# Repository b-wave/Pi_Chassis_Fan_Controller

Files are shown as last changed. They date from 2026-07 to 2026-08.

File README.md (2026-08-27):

# A Pi Chassis Fan Controller - Interface Board 
This describes a small board to interface a 5V, 4-wire fan in a controller cabinet with a Raspberry Pi controller.  The fan I am using is a **GeeekPi** 40x40x10mm 4-wire Fan, **Model F-0028**.  [https://www.amazon.com/GeeekPi-Raspberry-40x40x10mm-Adjustment-Included/dp/B0CL41RG93] 

The JST SH connector on the board should be compatible with the Raspberry Pi's Fan Connector. But that connector did not exist on a PI3. You **DO NOT** need this board to control the processor fan, it is intended to actively ventilate an enclosed, wall mounted cabinet. Yes, it is over-designed and has extras such as a static ring ground and ESD diodes - all are probably overkill but it is cheap insurance.  Yes, there are three revisions. I started with a two-wire fan, then three-wire, and finally with this 4-wire version with 100% less transistors.  It mainly just converts the short JST connector into a standard screw terminal. 

Although I provide a separate 2-pin input voltage connector terminal block (J3) it is intended for 5-Volts only. Its purpose is to not stress the **Raspberry Pi's** Power supply.  Although it should be perfectly fine to run the recommended fan directly off of the +5V, since it was designed to run off of the fan connector on the newer boards. 

By the way, that connector is reverse voltage protected in case you get the power leads reversed - you *should not* damage the Pi.

<h2 align="center">⚡ CAUTION ⚡</h2>

Be careful if using a 12V fan! *Damage may occur to 3v3 inputs and you may fry your Pi* 

It may need a **level shifter** if it does not provide 5V or pin compatible signals (TACH and maybe the PWM) - verify pin voltages before connecting to PI.  If they are open collector, the 3v3 reference on the 10k pullup should take care of that. 

<p align="center">
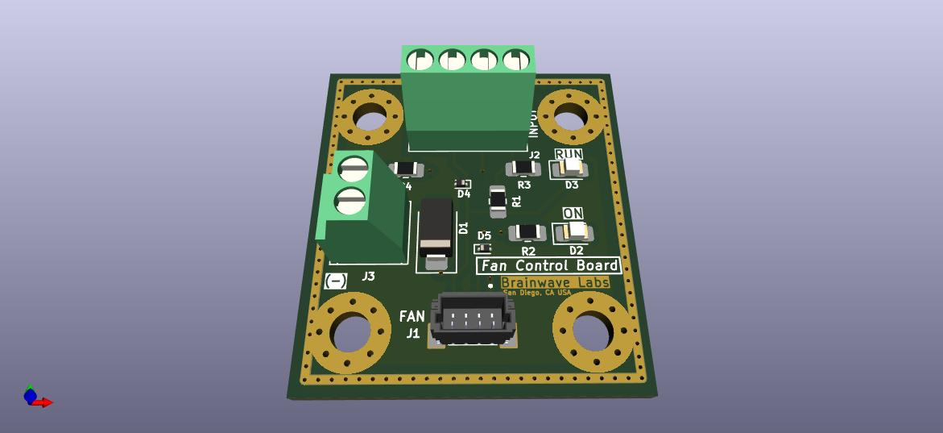
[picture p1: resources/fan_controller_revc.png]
3D View Generated
  
</p>

## Overview
I am working on a Raspberry Pi 4 controlled LTE gateway using a small DIN rail enclosure.  The planned locations are at fairly remote, and the equipment will be enclosed in a small cabinet so active ventilation is required.  This board was needed to simplify installation and to provide some visual and remote feedback.  This is a fairly simple board that is tailored to my specific installations, but I may expand it to be more general purpose.  In any case, it provides a neat interface to control a cabinet fan I finally settled on this design:

<p align="center">
  Schematic
</p>

The schematic is pretty straightforward.  It uses a hybrid SMT + Through-hole technologies. The ESD diodes wee exceedingly hard to hand solder *so I left them off the prototype,* but the rest of the board should be OK.  

---

## Hardware Description
The hardware combines familiar building blocks with some added protection from the very warm (hot) and dry environment.   I may put ESD tape and spray in my enclosure as it is intended to run in a dry dusty environment. 

  *I am not 100% sure if the "Ring Ground" is implemented correctly.  ...But it looks cool?*

<p align="center">
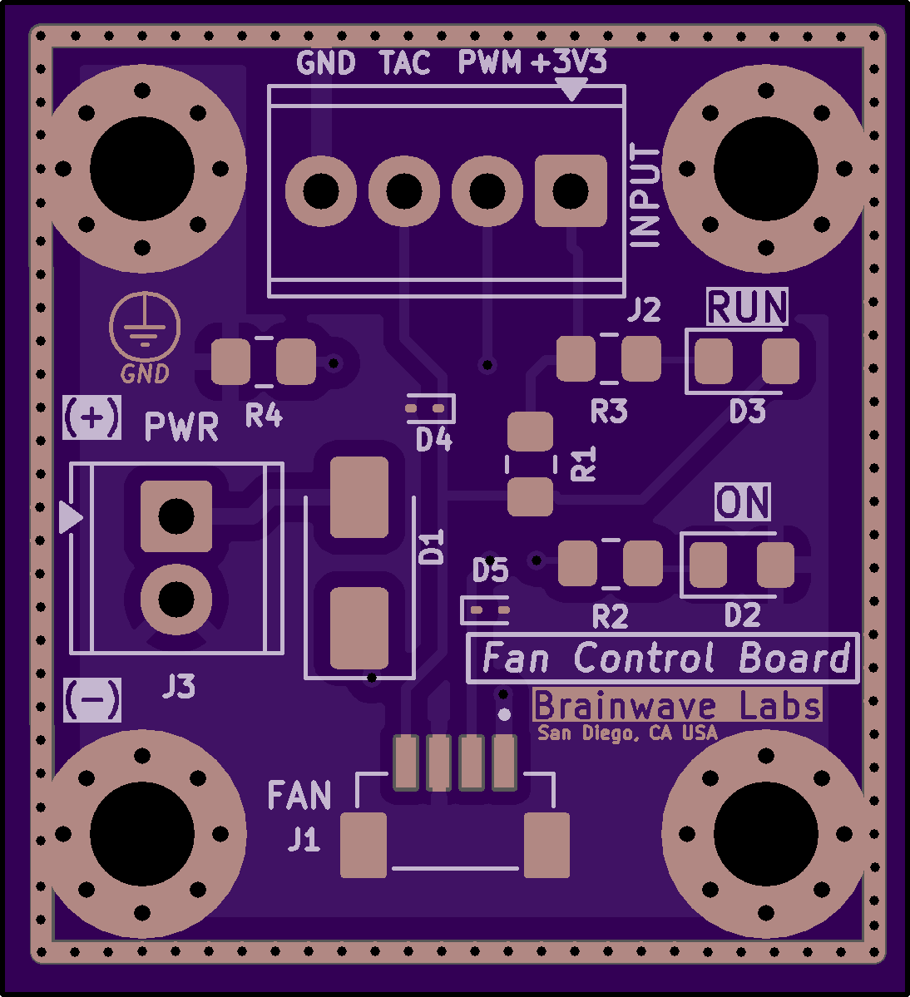
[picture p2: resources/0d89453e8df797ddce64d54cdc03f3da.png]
PCB
  
</p>

It is a approximately one inch square and is designed to fit on a small DIN rail carrier. The board is available on OSHPARK Shared and I will leave a link. [ www.oshpark](https://oshpark.com) ~The shown image is an early version and some components are moved. I will update and add a link after testing!~  

            Hole Spacing: 0.75" x 0.80" (19.0mm x 20.3mm)
            Board Outline: 1.10" x 1.20" (27.6mm x 30.2 mm)

  - The LEDs give a visual indication of the fan's operation, since in many cases the fan cannot be seen or heard. 

### Wiring: 
The fan controller interface board was designed with screw blocks so you can use wires (stranded 20-22 AWG is recommend) simply strip your wire tips back ~1/8", slide them into the screw terminals, and screw to clamp them down tightly. Alternately, DuPont jumper wires should work, acting like ferrules to keep the wires from pinching. Since these connectors are on 0.1" (2.54mm) centers so you can alternately use regular pin headers and DuPont jumpers.

### Input connector: 
This connector should be compatible with most 4-wire 5V cooling fans. It helps in two ways. First you just plug in the fan, it provides an interface for the fan's connector. Secondly, since this board is meant for use in an enclosure, the fan wires usually are not long enough, so simply locate this board near the fan and run longer wires back to the Pi.

### Power Connector: 
J3 pins may be used to input power for the fan. A second external power supply may be used to keep load off of the 5V Raspberry power supply. An external 5V supply should be used but it is possible to use a 12V fan but be mindful of the signals (TACH and PWM) may not have GPIO compatible levels.  But typically the TACH signal is an open collector (or Drain) type so you can use the pull up and the 3v3 reference will generate the proper input signal.  

 - Fan 5V Power (J3) Pin (1) (Red) ──► Screw into terminal 5V (Pin 2 or 4)
 - Fan 5V Ground (J3) Pin (2) (Black) ──► Screw into terminal GND (Pin 6, 9, or 14)
   *Or use an external 5V supply* 

### Signal Pins: 
J2 is the signal interface to the Raspberry PI's GPIOs needed to control and monitor the fan. Two GPIOs are needed, one output for the **PWM** and input for the **TAC (FG)** wires. 

 - Fan 3 Volt Reference (RED) ──► Screw into terminal (3V3)
 - Fan PWM Control Signal (Blue) ──► Screw into terminal GPIO 12 (Pin 32)
 - Fan System Ground (Black) ──► Screw into terminal GND (Pin 6, 9, or 14)
 - Fan TACH (or FG) Speed Feedback (Yellow) ──► Screw into terminal GPIO 13 (Pin 33)
  
    - **NOTE:**
      - The wire colors are fairly standard - but they should match the Pi-Fan connectors
      - If the PWM wire connection is open the fan will run at full speed. If you don't want that put a large (10k - 100k) resistor to ground 

### The "ON" LED: 
      
The "Fan On" or "Drive" Indicator (Green or Red)

This LED is wired to the PWM lines powering the fan. When the fan is running at full speed (100% PWM) it is ON full, when it is OFF ( 0% PWM) the fan is OFF. There is a slight dim glow green whenever the fan has power and is being driven by the PWM signal in different speeds it also changes brightness. 

  - **NOTE:** This LED can also be used to FLASH a code if the fan stalls to aid in servicing since it is strictly an output. 
  
### The "RUN" LED: 
The "Fan Spinning" Indicator (Yellow or Blue). 

This LED is wired to the TACH  line to monitor it visually. Sometimes this signal is labeled Frequency Generator (FG). 

When the fan is stalled or off, the LED either stays solid or completely dark. When the fan spins at high speed (e.g., 3000 RPM), the TACH pulses occur so quickly (100 times per second) that human eyes perceive the flashing as a continuous, soft glow. If the fan slows down or begins to struggle, you will visually notice the light dimming or starting to flicker.  If it stops with the LED ON it will turn off after a few seconds. this is normal behavior of these fans to protect against a stall it shuts the control circuits down.  It may even flash occasionally on some fans to test to see if the obstruction is clear. 

---

## Example Software

*Coming Soon! - no, really.  Check back*

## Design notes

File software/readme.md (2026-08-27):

# Example Scripts
These were generated scripts and some are not really tested. But you should be able to modify for your own use. 
--

## The Hardware Test Python Script 

**[fan_thermal_test.py]**

This Python script uses the **gpiozero** library to test the fan and the PCB. It reads the Pi SoC and the ambient temperature (via the RTC module). This script does work on my hardware but you may need to modify it to run. You should see a smooth linear climb for example: 
  
*Start at 0% duty cycle climbing to 750 RPM at 25% duty cycle up to a whopping 3,900 RPM at 100% means your PCB's hardware pull-up circuit and the software interrupt logic are working flawlessly.*

NOTE: 

- Some settings I used on my Raspberry Pi 3 system is running a development branch of Debian Trixie (Debian 13) with Linux kernel 6.18.34+rpt-rpi-v8
-   While 25,000 Hz (25kHz) is the ideal hardware standard for computer fans to prevent a high-pitched whining noise, a software-driven GPIO pin using lgpio cannot handle a frequency that high and throws a 'bad PWM frequency' error. So to bypass this error and see the fan spin, we can change the frequency down to a standard value that lgpio accepts, like 100 Hz. Because 100 Hz is in the human audible spectrum, the fan motor might make a faint humming sound during the test—this is completely normal for software PWM!
-   Also, the interface board has its own pull up resistor on the TACH line, so I turned off the pull up on the GPIO as well. 
   
```
# 25kHz is the industrial standard target frequency for 4-wire fans
fan_pwm = PWMOutputDevice(PWM_PIN, frequency=100, initial_value=0.0)
fan_tach = DigitalInputDevice(TACH_PIN, pull_up=None, active_state=False) # Using the PCB's 3V3 hardware pull-up
```

## The Failsafe Monitoring Python Script

**[Fan_Failsafe_Monitor.py]**

This Python script uses the gpiozero library to watch for pulses on the FG pin. It calculates the RPM, and if the fan is supposed to be running but stalls out (RPM drops to 0), it triggers your power-saving protective mode
--

## System Test with Logging and Alerts Python Script

**[Fan_System_Test_Example.py]**
This is an example operational/test script hat reads temperatures from two points in the chassis, the SoC and the ambient temperature (the termal sensor in the RTC chip) to help define and set the setpoints.  The test's alerts are shown with ntfy.com  
--

##  Complete Automated Python Script

**[Fan_Control.py]**
This script uses the gpiozero library to handle both pins. It samples the Raspberry Pi's internal CPU temperature every few seconds. If the Pi gets warm, it turns on the fan and scales the fan's speed using PWM. If the Pi cools down, it shuts off the fan completely  (PWM = 0%) to save power.
--

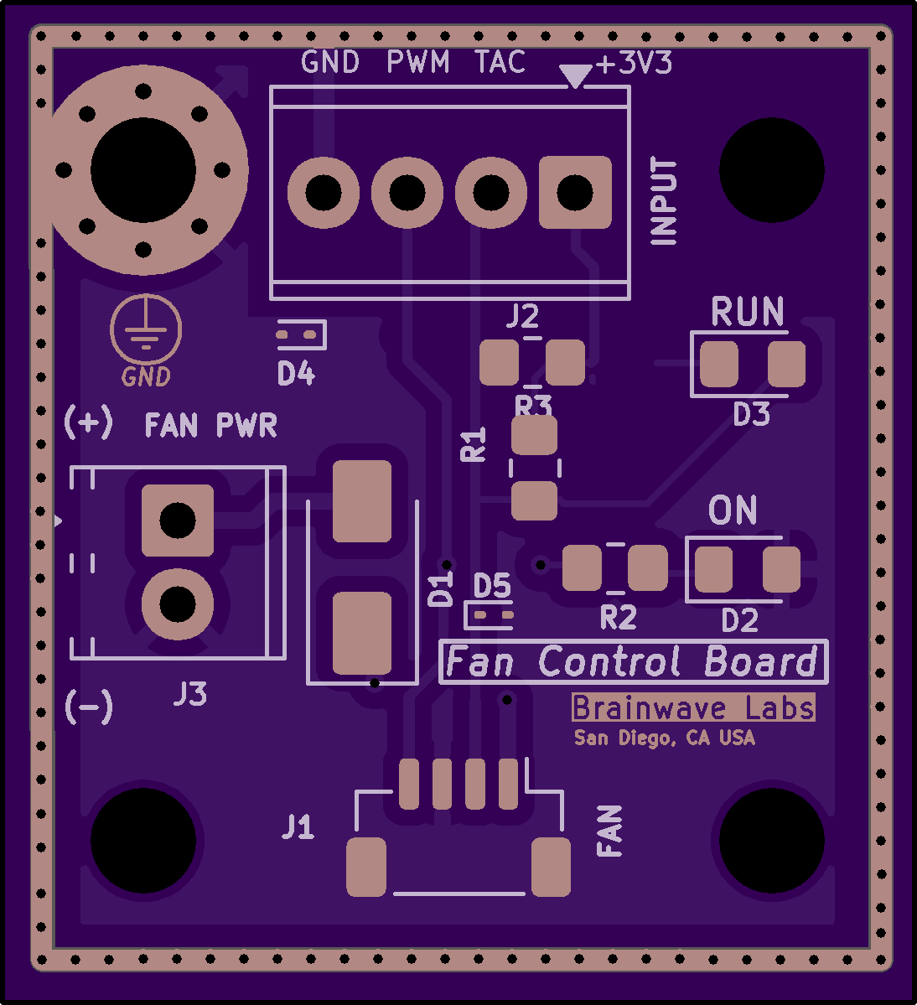
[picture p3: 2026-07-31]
resources/f2cf50859baaec17621ed978b20d583c.png

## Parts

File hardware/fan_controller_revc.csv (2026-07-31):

Reference | Value | Footprint | Datasheet | Qty | DNP | Exclude from BOM | Exclude from Board
D1 | SS14 | Library:D_SMA | https://www.digikey.com/en/products/detail/onsemi/SS14/965474 | 1
D2 | ON | Library:LED_0805_2012Metric_Pad1.15x1.40mm_HandSolder | ~https://www.digikey.com/en/products/detail/liteon/LTST-C190KGKT/386815 | 1
D3 | RUN | Library:LED_0805_2012Metric_Pad1.15x1.40mm_HandSolder | https://www.digikey.com/en/products/detail/liteon/LTST-C190KSKT/386819 | 1
D4 | ESD9B3.3ST5G | Diode_SMD:D_SOD-923 | https://www.digikey.com/en/products/detail/onsemi/ESD9R3-3ST5G/1961067 | 1
D5 | ESD9B3.3ST5G | Library:D_SOD-923 | https://www.digikey.com/en/products/detail/onsemi/ESD9R3-3ST5G/1961067 | 1
H1,H2,H4 | MountingHole | Library:MountingHole_3.2mm_M3_DIN965 | ~ | 3 |  | Excluded from BOM
H3 | MountingHole_Pad | Library:MountingHole_3.2mm_M3_Pad_Via | See Note | 1 |  | Excluded from BOM
J1 | FAN | Library:ADAFRUIT_4328 | https://www.digikey.com/en/products/detail/jst-sales-america-inc/BM04B-SRSS-TB/926696 | 1
J2 | INPUT | Library:TerminalBlock_Phoenix_MPT-0,5-4-2.54_1x04_P2.54mm_Horizontal | https://www.digikey.com/en/products/detail/on-shore-technology-inc/OSTVN04A150/1588864 | 1
J3 | PWR | Library:TerminalBlock_Phoenix_MPT-0,5-2-2.54_1x02_P2.54mm_Horizontal | ~https://www.digikey.com/en/products/detail/adafruit-industries-llc/2138/6827101 | 1
R1 | 10k | Library:R_0805_2012Metric_Pad1.20x1.40mm_HandSolder | https://www.digikey.com/en/products/detail/vishay-dale/CRCW080510K0FKEA/1175751 | 1
R2,R3 | 1K | Library:R_0805_2012Metric_Pad1.20x1.40mm_HandSolder | https://www.digikey.com/en/products/detail/vishay-dale/CRCW08051K00FKEA/1175637 | 2

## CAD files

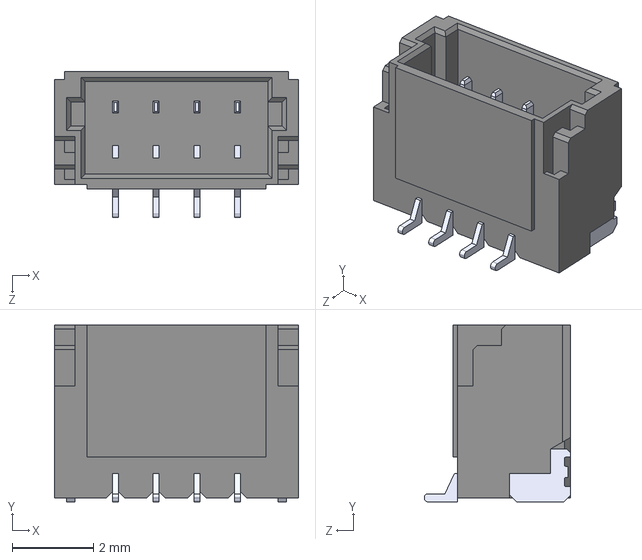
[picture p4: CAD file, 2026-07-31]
hardware/4328/4328.step
6.00 x 4.35 x 3.60 mm

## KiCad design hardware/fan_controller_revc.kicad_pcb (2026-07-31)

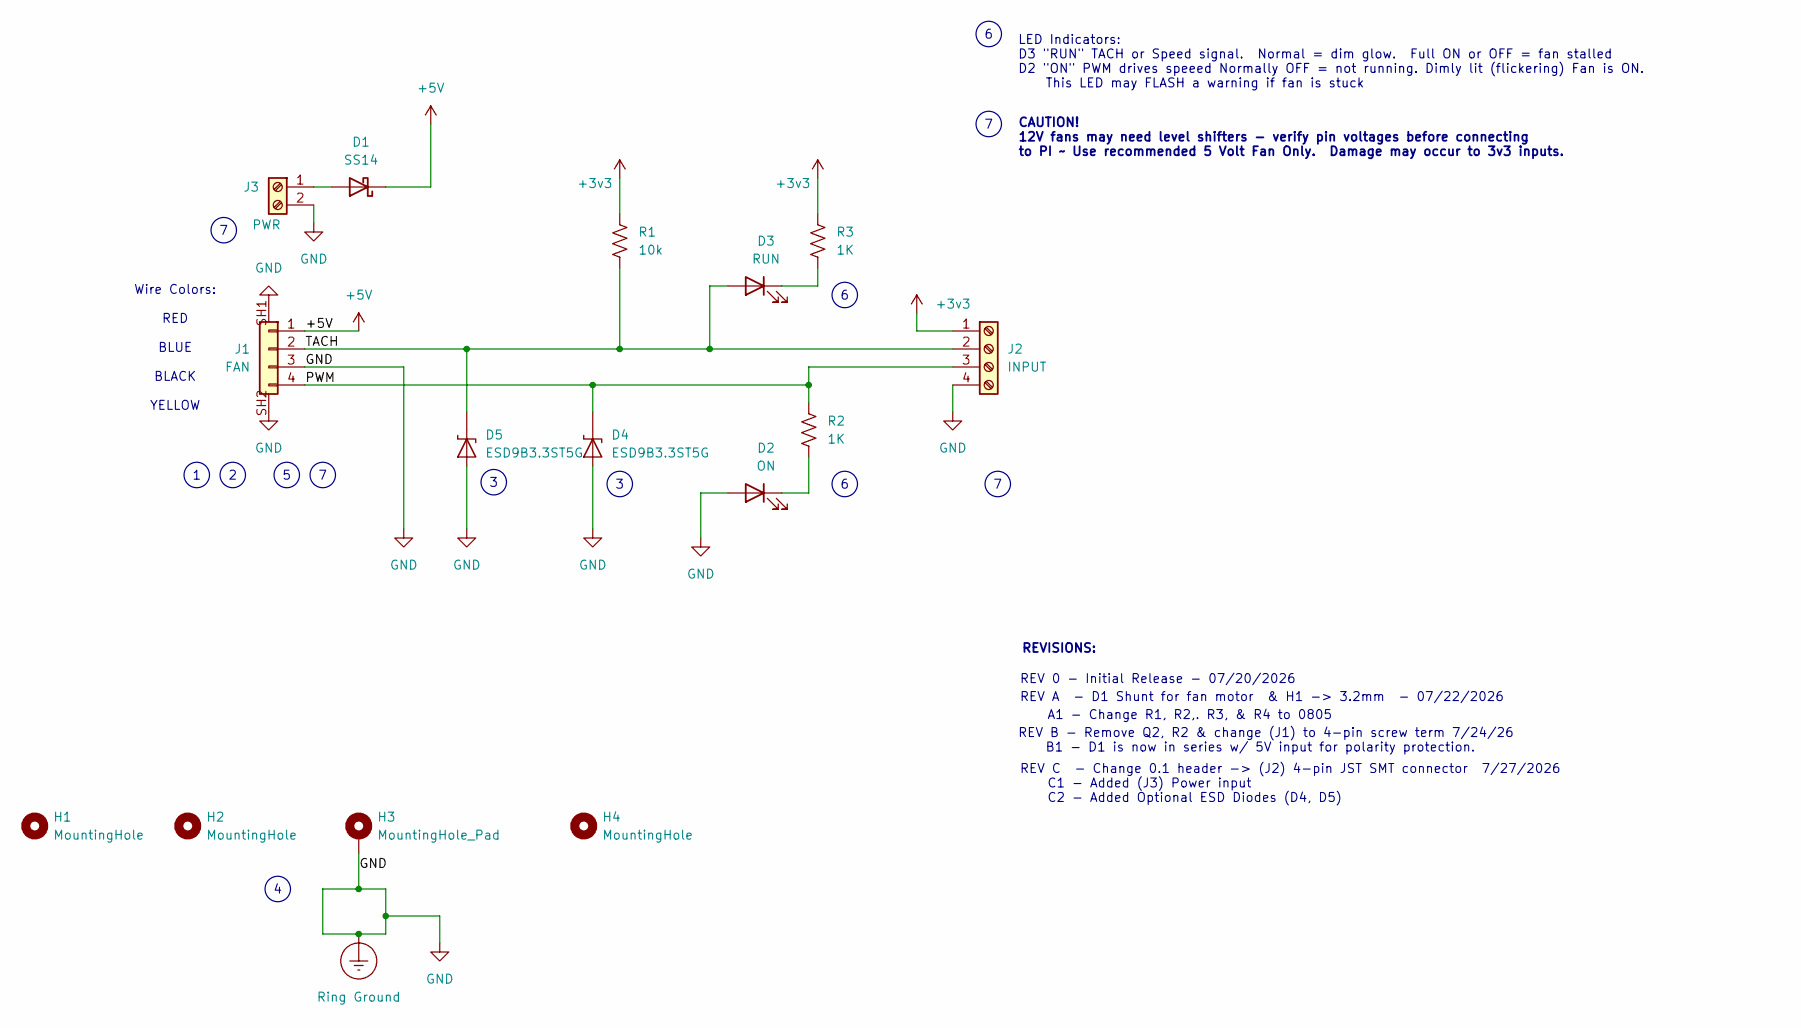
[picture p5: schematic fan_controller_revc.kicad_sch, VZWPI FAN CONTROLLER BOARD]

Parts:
D1: SS14; D_SMA
D2: ON; LED_0805_2012Metric_Pad1.15x1.40mm_HandSolder
D3: RUN; LED_0805_2012Metric_Pad1.15x1.40mm_HandSolder
D4, D5: ESD9B3.3ST5G; D_SOD-923
H1, H2, H4: MountingHole; MountingHole_3.2mm_M3_DIN965
H3: MountingHole_Pad; MountingHole_3.2mm_M3_Pad_Via
J1: FAN; ADAFRUIT_4328
J2: INPUT; TerminalBlock_Phoenix_MPT-0,5-4-2.54_1x04_P2.54mm_Horizontal
J3: PWR; TerminalBlock_Phoenix_MPT-0,5-2-2.54_1x02_P2.54mm_Horizontal
R1: 10k; R_0805_2012Metric_Pad1.20x1.40mm_HandSolder
R2, R3: 1K; R_0805_2012Metric_Pad1.20x1.40mm_HandSolder

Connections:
+3v3: J2.1, R1.1, R3.1
+5V: D1.1 (K), J1.1
/PWM: D4.1 (k), J1.4, J2.3, R2.2
/TACH: D3.2 (A), D5.1 (k), J1.2, J2.2, R1.2
GND: D2.2 (A), D4.2 (k), D5.2 (k), H3.1, J1.3, J1.SH1, J1.SH2, J2.4, J3.2
unnamed: D1.2 (A), J3.1
unnamed: D2.1 (K), R2.1
unnamed: D3.1 (K), R3.2

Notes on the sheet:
Wire Colors: RED BLUE BLACK YELLOW
A1 - Change R1, R2,. R3, & R4 to 0805
REVISIONS:
REV C - Change 0.1 header -> (J2) 4-pin JST SMT connector 7/27/2026 C1 - Added (J3) Power input C2 - Added Optional ESD Diodes (D4, D5)
LED Indicators: D3 "RUN" TACH or Speed signal. Normal = dim glow. Full ON or OFF = fan stalled D2 "ON" PWM drives speeed Normally OFF = not running. Dimly lit (flickering) Fan is ON. This LED may FLASH a warning if fan is stuck
REV 0 - Initial Release - 07/20/2026
REV A - D1 Shunt for fan motor & H1 -> 3.2mm - 07/22/2026
REV B - Remove Q2, R2 & change (J1) to 4-pin screw term 7/24/26 B1 - D1 is now in series w/ 5V input for polarity protection.
CAUTION! 12V fans may need level shifters - verify pin voltages before connecting to PI ~ Use recommended 5 Volt Fan Only. Damage may occur to 3v3 inputs.

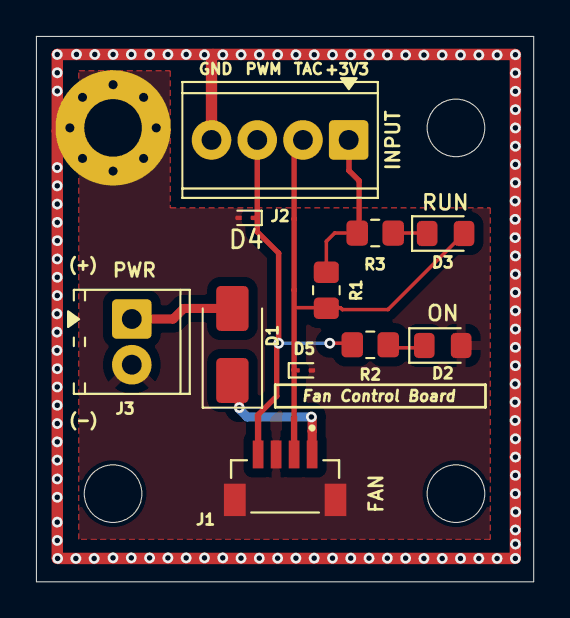
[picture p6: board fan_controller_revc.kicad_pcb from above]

Board: 2 copper layers, 27.6 x 30.3 mm, 15 parts (0 on the bottom side), 8 nets.

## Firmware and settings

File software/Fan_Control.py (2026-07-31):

import time
from gpiozero import PWMOutputDevice, OutputDevice, CPUTemperature

# --- CONFIGURATION ---
PWM_PIN = 12       # GPIO Pin connected directly to the fan's 3rd wire
ENABLE_PIN = 13    # GPIO Pin connected to the 1kΩ resistor -> NPN Transistor Base

TEMP_MIN = 50.0    # Temperature (°C) where the fan turns on at lowest speed
TEMP_MAX = 70.0    # Temperature (°C) where the fan hits 100% maximum speed

# --- INITIALIZATION ---
# Active_high=True means setting the pin to True turns the transistor ON
fan_power = OutputDevice(ENABLE_PIN, active_high=True, initial_value=False)

# Initialize PWM with a standard 25kHz frequency suitable for fan controllers
fan_speed = PWMOutputDevice(PWM_PIN, frequency=25000, initial_value=0.0)

cpu = CPUTemperature()

print("Automated thermal chassis management started...")

try:
    while True:
        current_temp = cpu.temperature
        print(f"Current CPU Temp: {current_temp:.1f}°C")

        if current_temp < TEMP_MIN:
            # Pi is cool: Shut off PWM and cut the transistor ground completely
            fan_speed.value = 0.0
            fan_power.off()
            print("Chassis Cool: Fan completely powered down.")
            
        else:
            # Pi is warm: Ensure the transistor is active and grounding the fan
            if not fan_power.value:
                fan_power.on()
                time.sleep(0.1) # Brief pause to let power stabilize
            
            # Linear scaling formula to map temperature to a 0.0 - 1.0 PWM range
            scaled_speed = (current_temp - TEMP_MIN) / (TEMP_MAX - TEMP_MIN)
            
            # Constrain the speed between 20% minimum (to keep it spinning) and 100% max
            target_pwm = max(0.2, min(1.0, scaled_speed))
            
            fan_speed.value = target_pwm
            print(f"Chassis Warm: Fan power active. Speed set to {int(target_pwm * 100)}%")

        # Wait 5 seconds before sampling the temperature again
        time.sleep(5.0)

except KeyboardInterrupt:
    print("\nStopping script. Resetting fan pins...")
    fan_speed.close()
    fan_power.close()

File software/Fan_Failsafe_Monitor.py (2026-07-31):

import time
from gpiozero import Button
import subprocess

# --- CONFIGURATION ---
TACH_PIN = 23          # Change to whichever GPIO pin you used
PULSES_PER_REV = 2     # Standard PC/chassis fans output 2 pulses per revolution
CHECK_INTERVAL = 3.0   # How often to check the fan status (seconds)

# Keep track of pulses detected by the pin
pulse_count = 0

def count_pulse():
    global pulse_count
    pulse_count += 1

# Initialize the pin using gpiozero's Button class
# This automatically enables the safe internal 3.3V pull-up resistor
tach_wire = Button(TACH_PIN, pull_up=True)
tach_wire.when_pressed = count_pulse

print("Failsafe monitoring started. Watching for fan stalls...")

try:
    while True:
        # Reset pulse counter and wait for the tracking interval
        pulse_count = 0
        time.sleep(CHECK_INTERVAL)
        
        # Calculate RPM
        # Formula: (Pulses / Seconds) * 60 seconds / Pulses Per Revolution
        frequency = pulse_count / CHECK_INTERVAL
        rpm = (frequency * 60) / PULSES_PER_REV
        
        print(f"Current Fan Speed: {int(rpm)} RPM")
        
        # --- STALL DETECTION LOGIC ---
        # If the fan reads 0 RPM, execute safety fallback commands
        if rpm == 0:
            print("WARNING: Fan stall detected! Engaging power-saving mode.")
            
            # Example: Force Raspberry Pi CPU into low-power 'powersave' governor
            # (Requires running script with sudo)
            subprocess.run([
                "sudo", "cpufreq-set", "-g", "powersave"
            ], capture_output=True)
            
            # Alternate option: You could trigger a safe shutdown instead
            # subprocess.run(["sudo", "shutdown", "-h", "now"])
            
            break # Exit script after triggering failsafe

except KeyboardInterrupt:
    print("\nMonitoring stopped by user.")

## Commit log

2026-07-31 Enhance readme with fan stall testing instructions
    Added a testing note for fan stall in the readme.
2026-08-01 Revise README for Pi Chassis Fan Controller
    Updated README to enhance clarity and detail about the Pi Chassis Fan Controller, including specifications and LED indicators.
2026-08-06 Add wiring instructions for fan controller interface
    Added wiring instructions for the fan controller interface board, including pin assignments and notes on wire connections.
2026-08-11 Enhance README with wiring and connector details
    Expanded wiring instructions and added details about connectors and LED indicators.
2026-08-27 Fix typos and enhance README details
    Corrected the spelling of 'GeekPi' and added a link to the product. Updated notes on ESD protection and fan operation.
2026-08-27 Revise README for clarity and additional details
    Updated README to clarify compatibility and usage details for the fan controller board, including voltage protection and design revisions.
